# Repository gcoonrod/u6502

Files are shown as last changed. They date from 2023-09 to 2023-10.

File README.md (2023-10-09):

# u6502 - Single Board Computer
Very basic 6502 SBC based on the [design](http://wilsonminesco.com/6502primer/potpourri.html#BAS_CPU) by Garth Wilson.

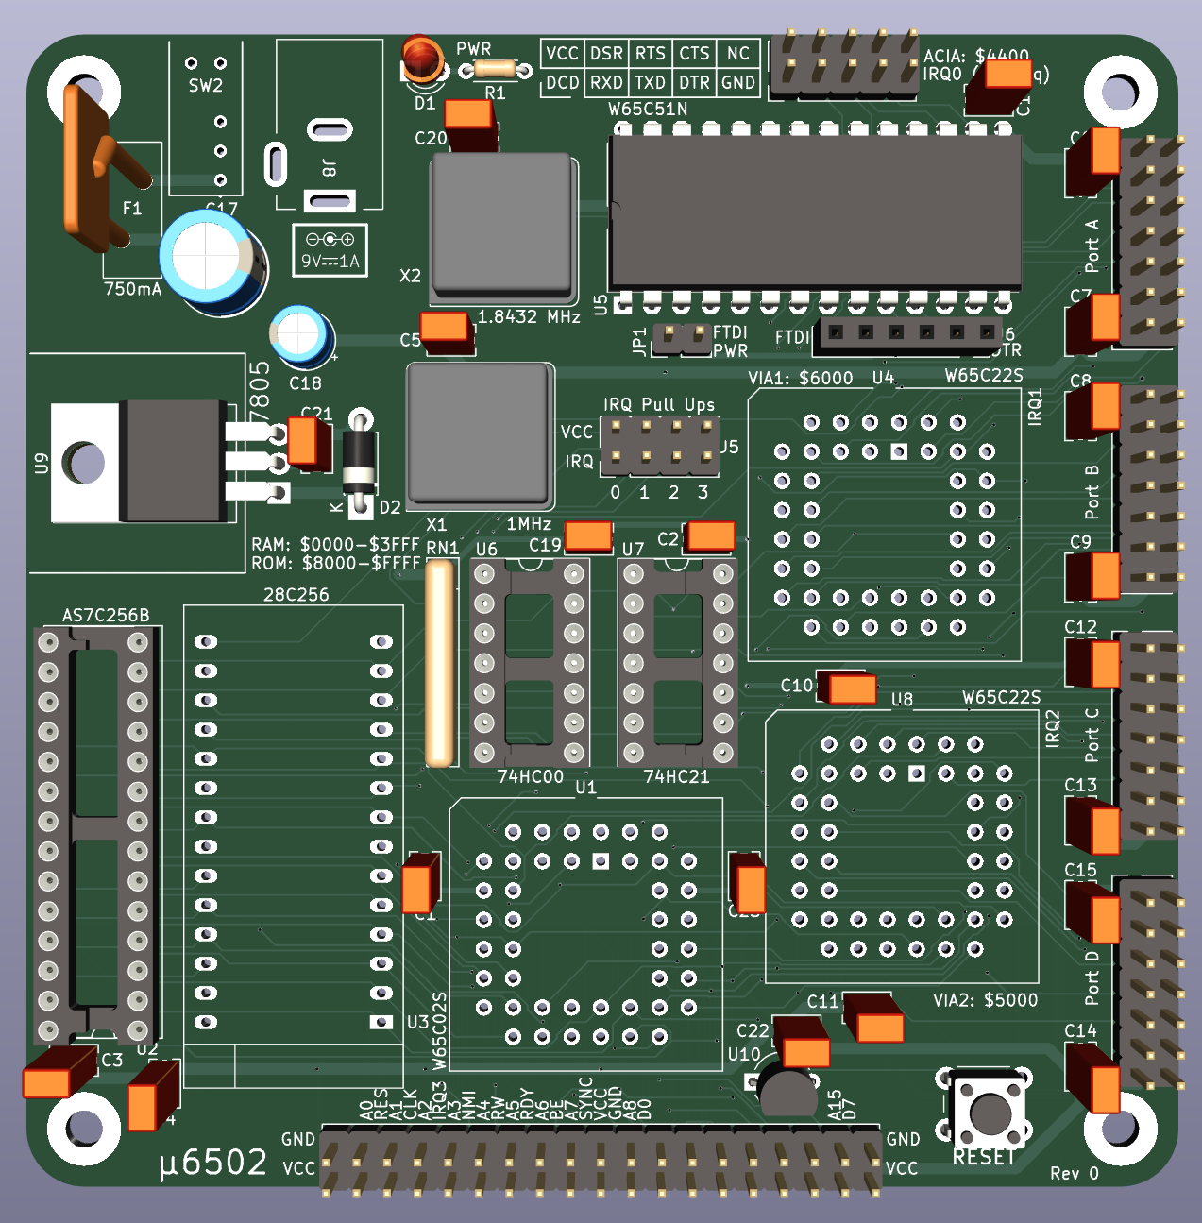
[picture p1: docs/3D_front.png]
PCB Render


## Project Status
A rev 0 board has been fabricated and assembled. Testing is in progress.

### Known Issues
- **LCD Display** - The LCD display correctly shows the two lines that are expected at power up but only displays a single line after a reset. Assumed to be a software issue involving the initialization logic for the LCD controller.
- **ACIA** - No TX traffic is observed from the ACIA. Currently unable to determine the reason. A logic analyzer connected to the chip select and register select signals for the ACIA _seem_ to indicate that the chip is being addressed correctly.

## Design Goals & Project Objectives

- Keep it _almost_ as simple as possible.
    - Start with a proven design to reduce the likelihood of errors.
    - Keep PCB size to less than 100mm^2 to minimize fabrication cost.
    - Use only parts that are currently in production and favor through hole components where possible.
- Support TTL RS232 UART with RTS/CTS flow control.
    - Allow for the loading of programs to memory from serial.
- Support PS2 protocol for keyboard through VIA.
- Support 16 x 2 character LCD display through VIA.
    - (Optional) Support larger character or graphics LCD display.
- (Optional) Support >4 MHz CPU speed.

## Repository Structure

- [boards](./boards/) - Kicad projects containing schematics and layout files for the SBC and any ancillary support devices.
- [docs](./docs/) - Documentation and static assests for the current iteration of the u6502.
- [firmware](./firmware/) - 6502 assembly files and build tooling (cc65) to produce ROMs for the u6502.
- [tools](./tools/) - Software utilities and Arduino sketches used to support the testing and development of the u6502.

## Addres Map

- RAM $0000:3FFF
- ACIA $4400:4403
- VIA2 $5000:500F
- VIA1 $6000:600F
- ROM $8000:FFFF

## Parts Selection

- CPU - W65C02S (PLCC) WDC current production 65C02
- Memory - AS7C256B-15PIN (DIP) SRAM chosen for package size more than speed
- ROM - Any 28C256 JEDEC compatible EEPROM (DIP) 
- Address Decoding - 74HC00 (DIP)
- IRQ Control - 74HC21 (DIP)
- GPIO - 2 W65C22S VIAs (PLCC)
- Serial IO - W65C51N ACIA (DIP)
- Power Regulation - LM7805 (TO220) compatible linear regulator
- Oscillators - 1MHz CPU clock & 1.8432 MHz for baud clock generation
- Reset control - DS1813 (TO92)

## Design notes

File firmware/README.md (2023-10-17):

# u6502 - Firmware

This directory contains the various programs, libraries, and utilities used by the u6502 SBC. 

## Build Process
Currently, all programs for the u6502 are assembled using the ca65 macro assembler which is a part of the [cc65 C Compiler](https://cc65.github.io/) project. ROMs are built in the following two step process:

1. Assembly - `ca65 -vvv --cpu 6502 -l {listingFilePath} -o {outputObjectFilePath} {sourceFilePath}`
2. Linking - `ld65 -o {outputBinaryPath} -C {linkerConfigFilePath} "{objectFilePath}"`
3. Flashing - The output from the linker is a binary that can be burned to the EEPROM (U3). This binary should work with any number of EEPROM programers, but I have only tested it with Xgpro.

A simple PowerShell script [build.ps1](build.ps1) is used to automate the build process in a Windows build environment. Usage of this script requires that the cc65 binaries be in the PATH environment variable. When using this script all output will go into the `build` directory.

### Linker Configuration
The cc65 linker (`ld65`) uses a configuration file to properly layout all of the assembled sources into a single output binary. I don't fully understand the syntax and capabilities of this configuration tool, but the [documentation](https://cc65.github.io/doc/ld65.html) is fairly good. In the case of the u6502, `roms/common/memmap.cfg` is the linker configuration. Of most importance here are the `MEMORY` and `SEGMENTS` sections which define the system's memory map and correlate any segments used in the assembly files with the correct memory locations.

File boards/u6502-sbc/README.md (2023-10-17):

# u6502 - SBC PCB Design Project
Kicad project for u6502.

[Schematic](../../docs/schematic.pdf)

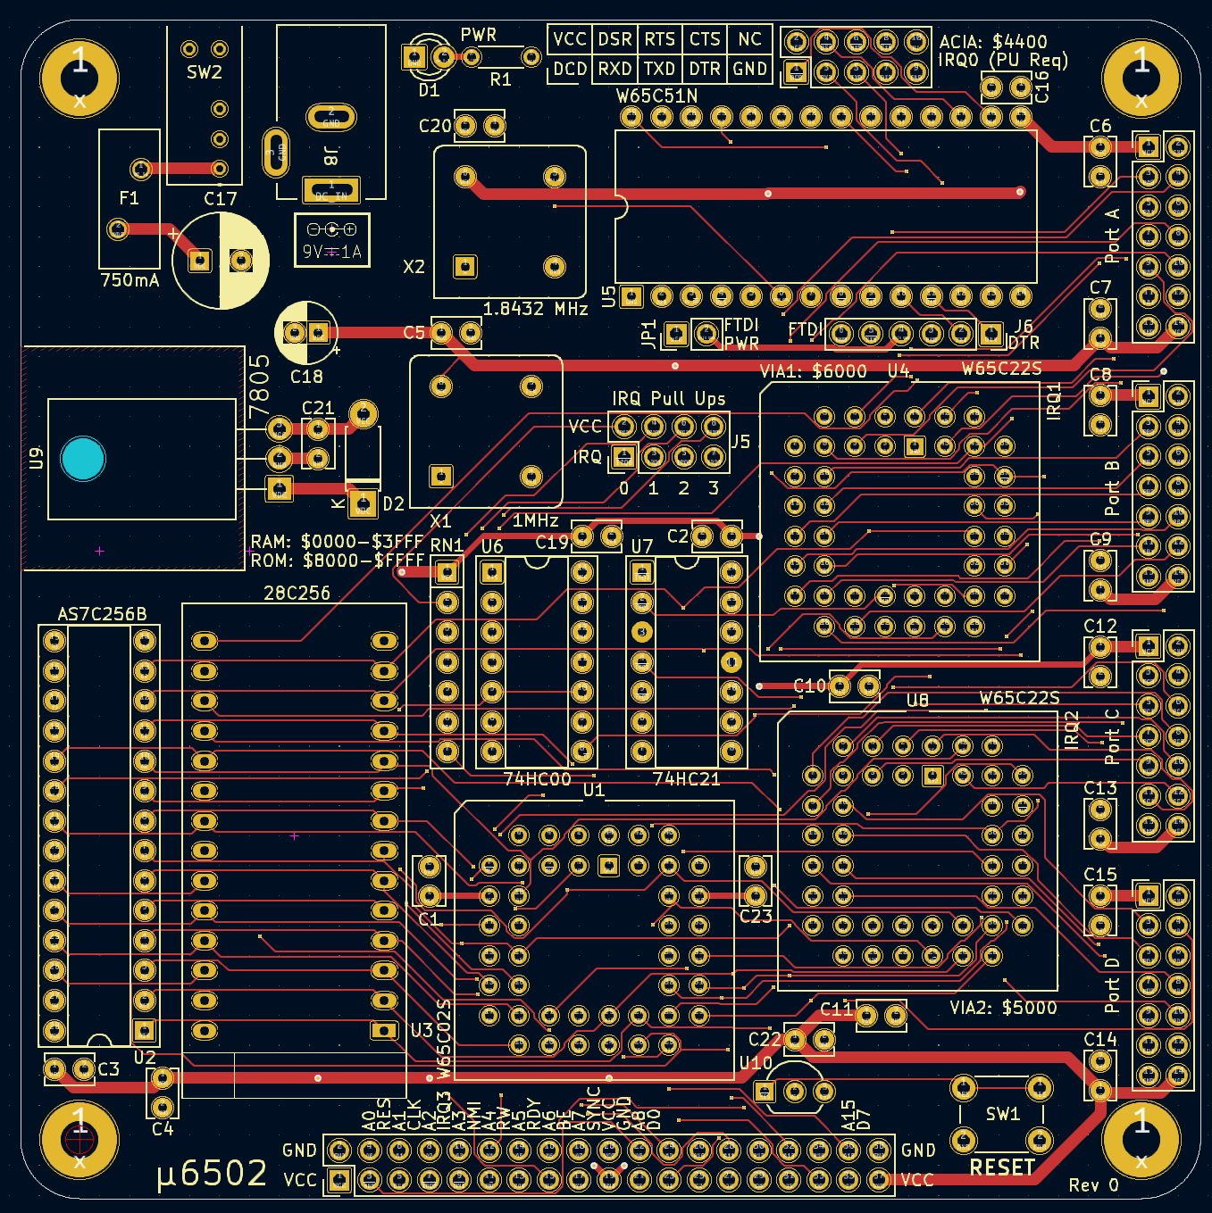
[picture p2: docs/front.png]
Front


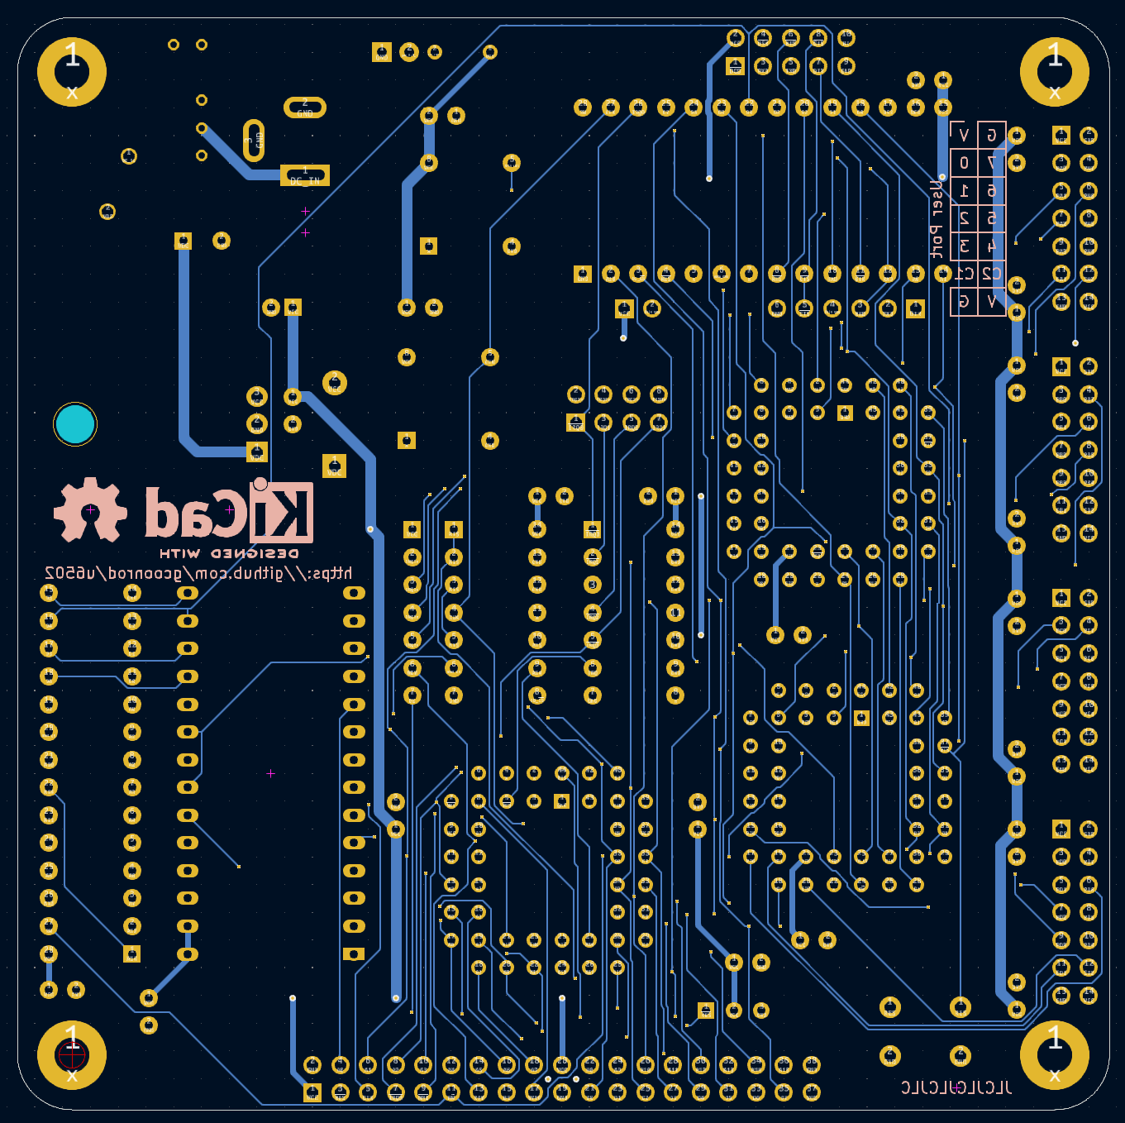
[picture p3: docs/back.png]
Back


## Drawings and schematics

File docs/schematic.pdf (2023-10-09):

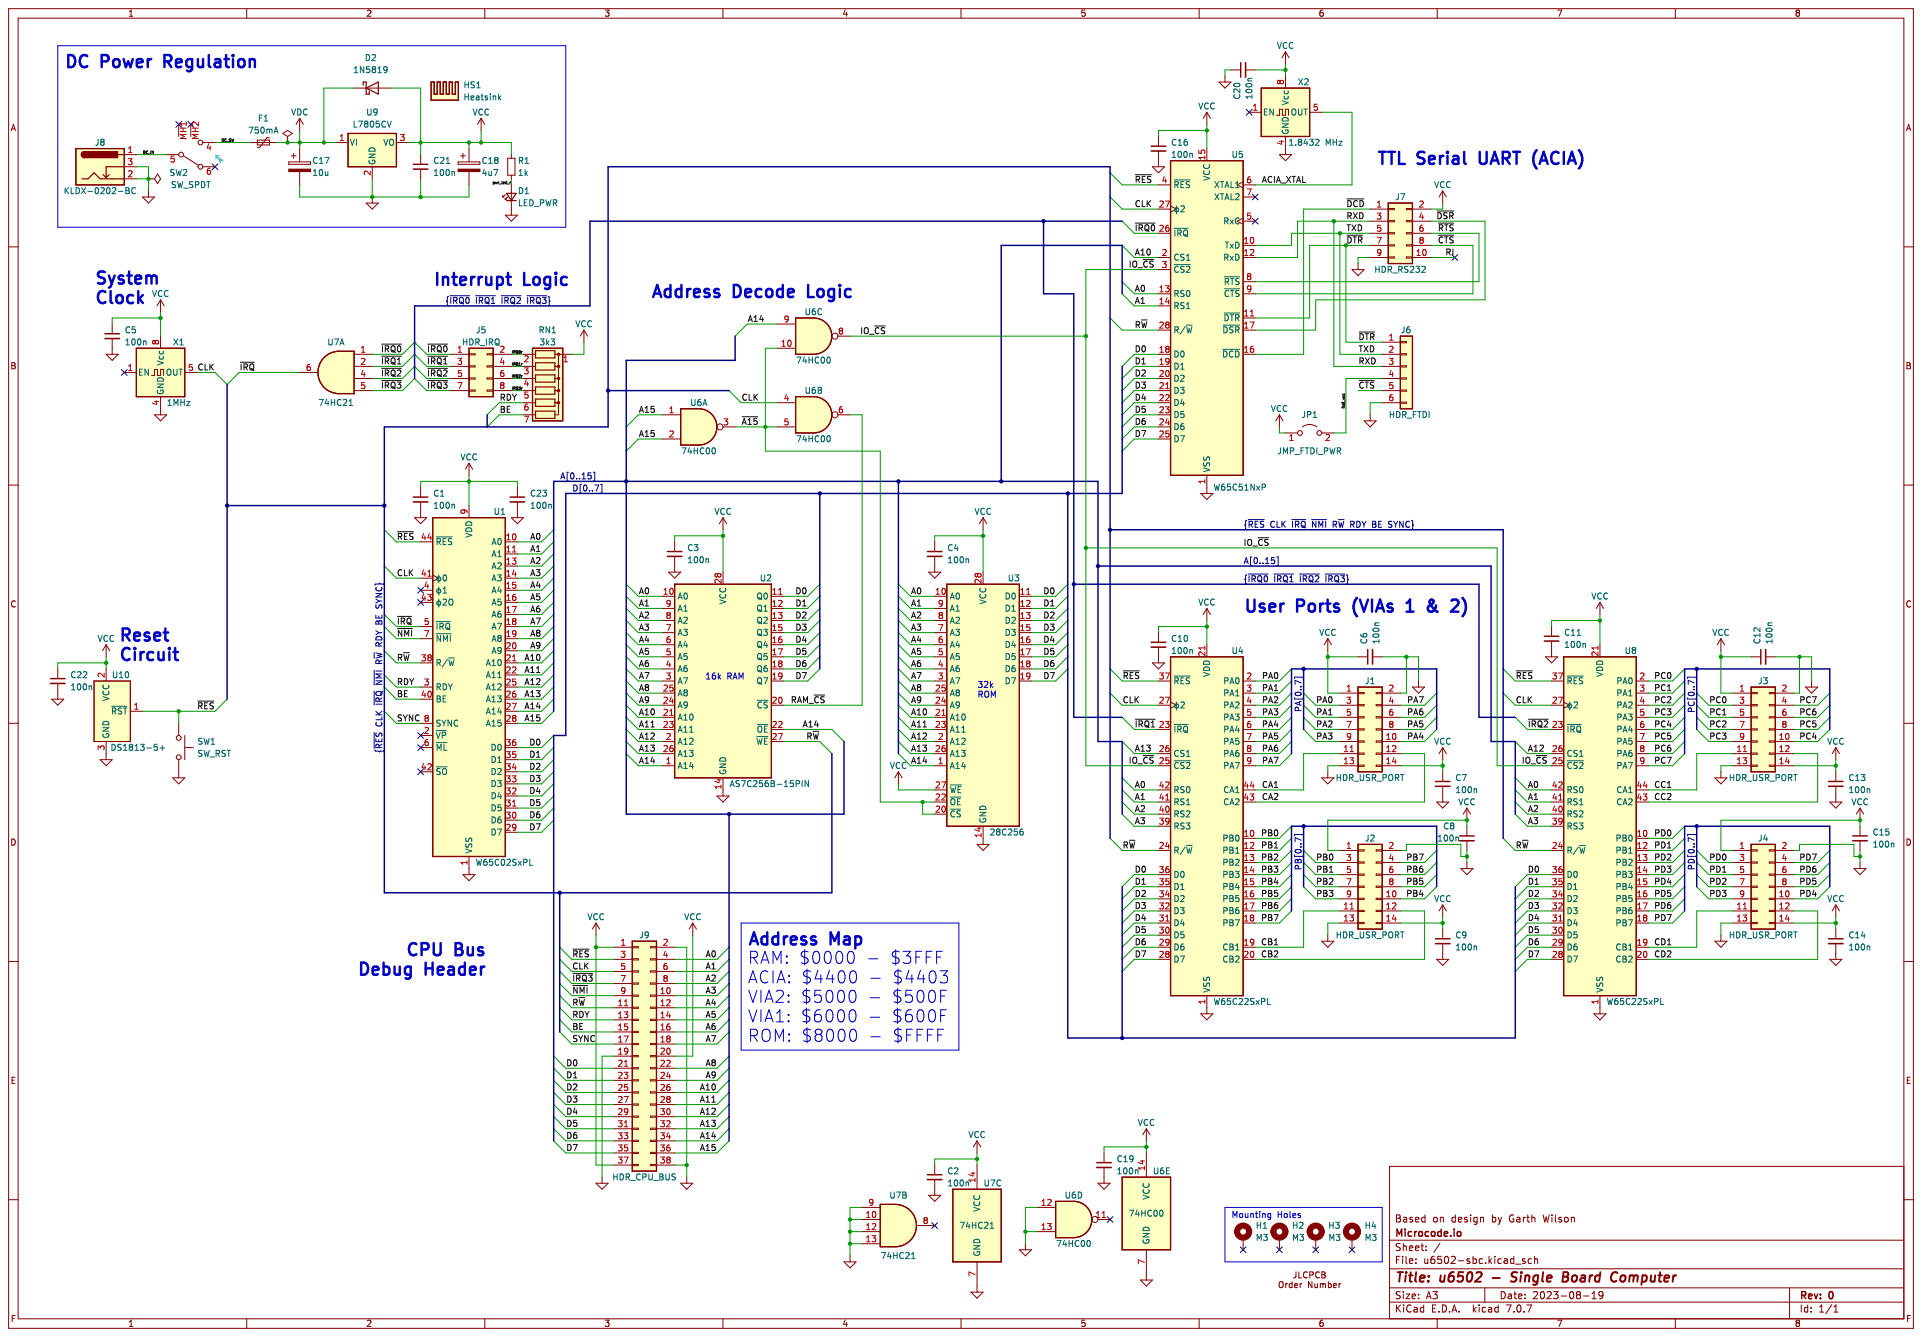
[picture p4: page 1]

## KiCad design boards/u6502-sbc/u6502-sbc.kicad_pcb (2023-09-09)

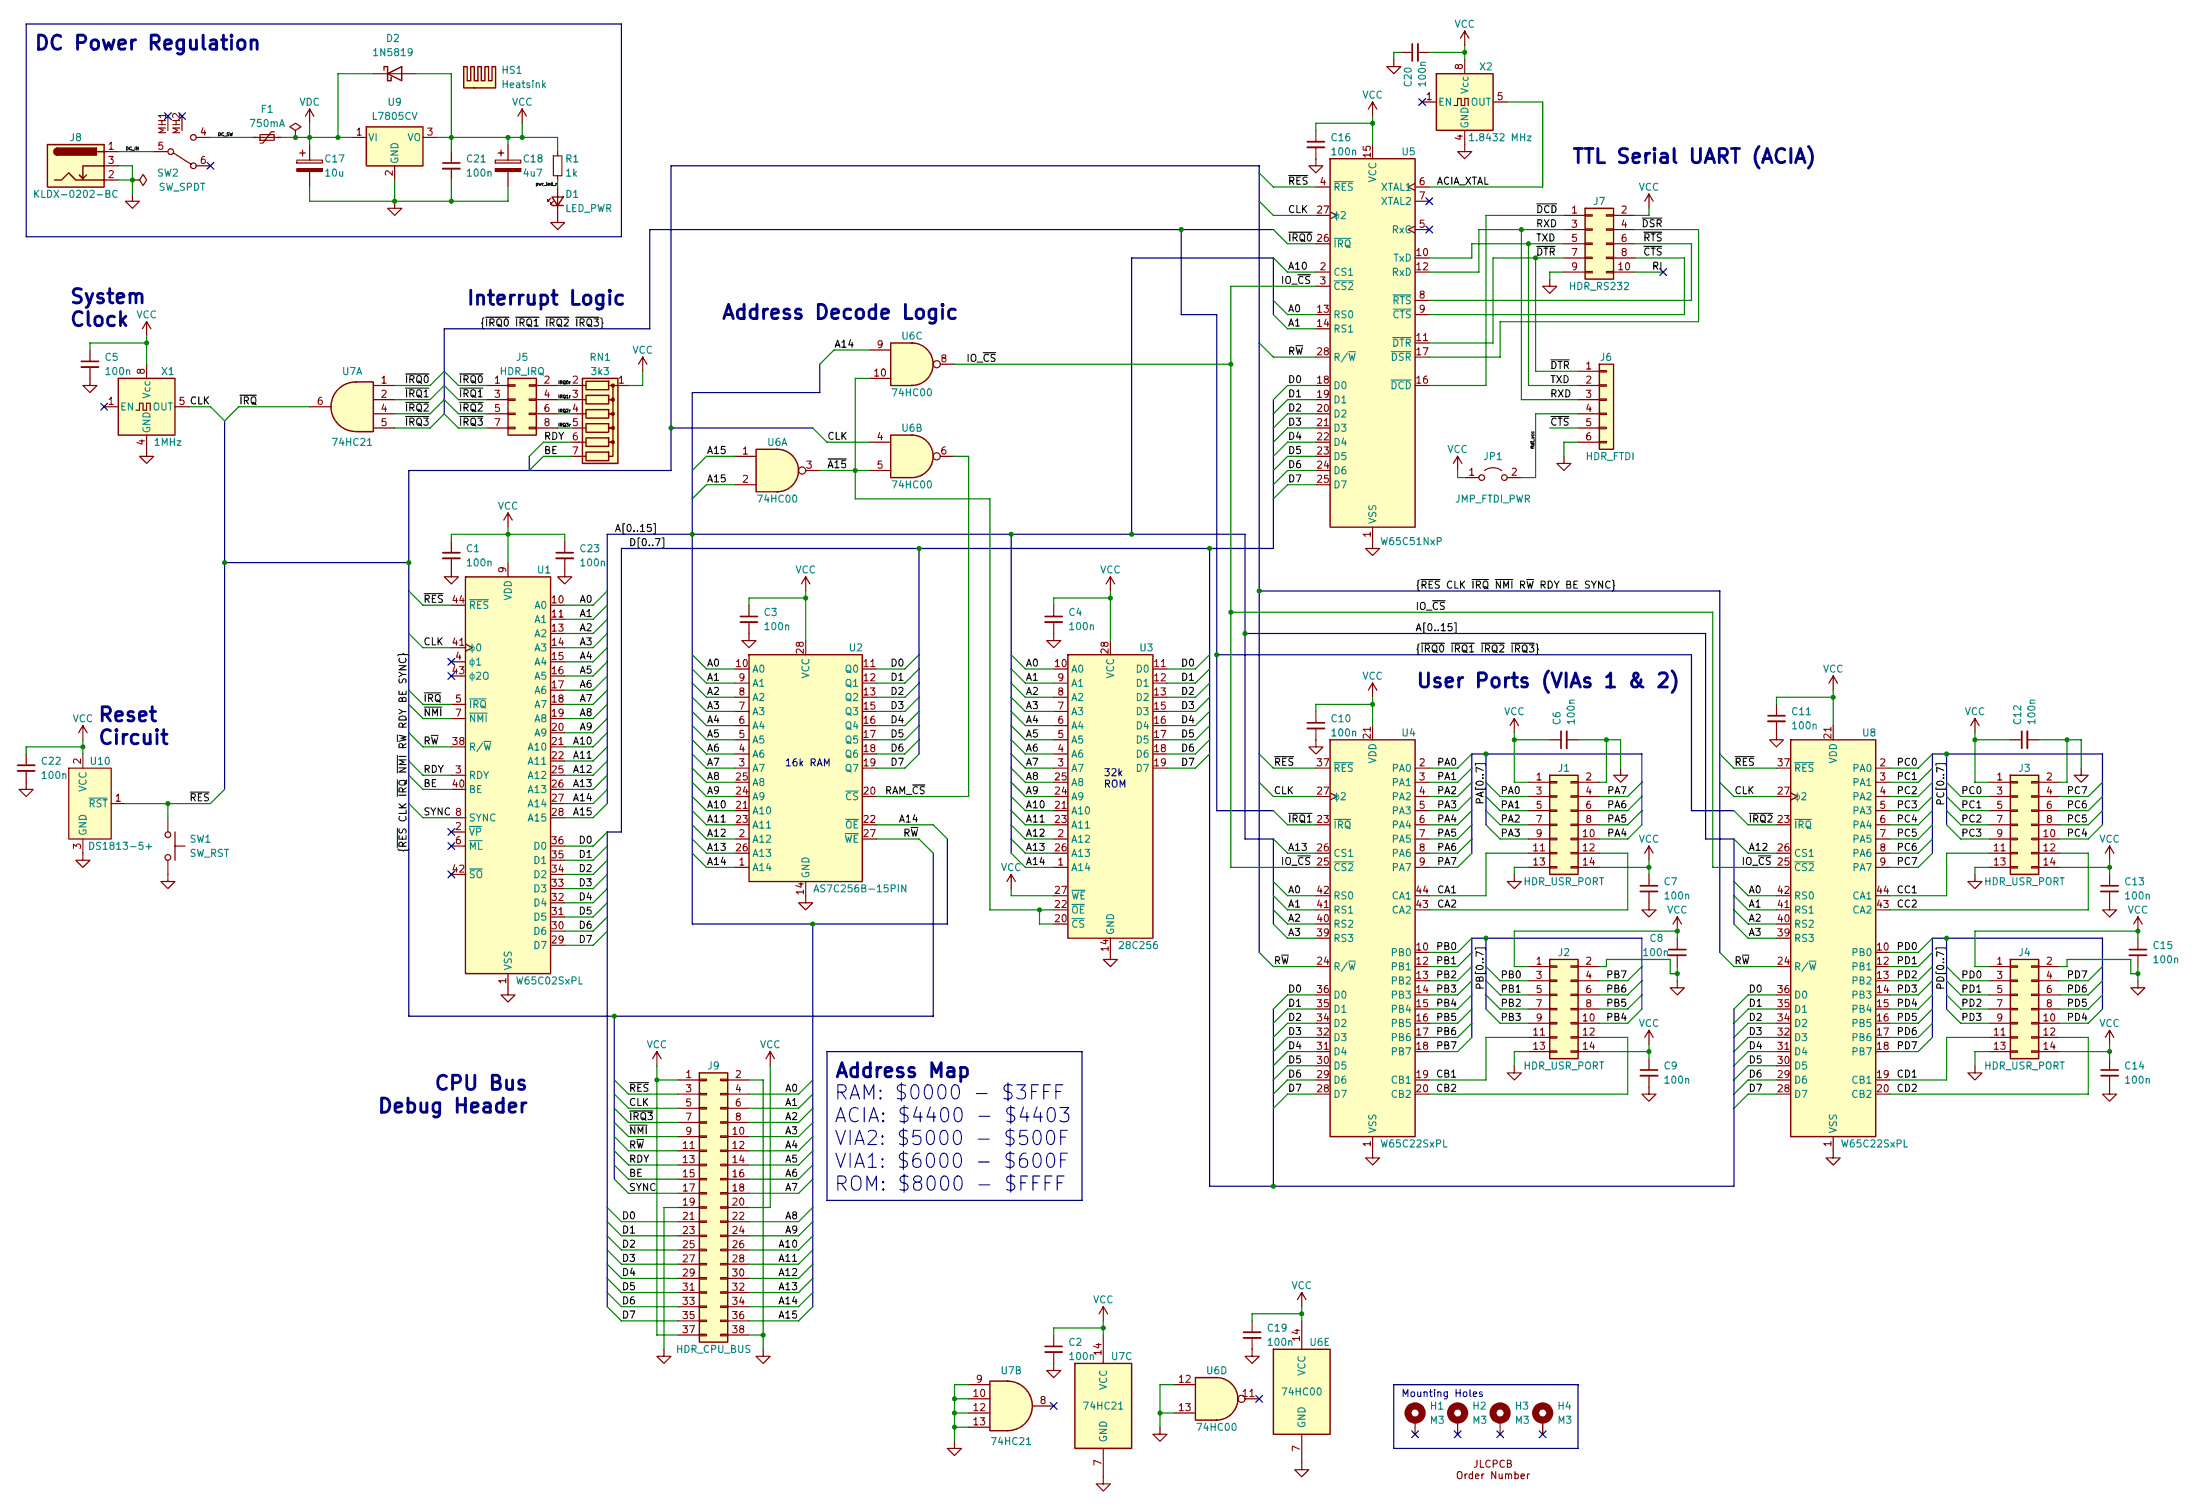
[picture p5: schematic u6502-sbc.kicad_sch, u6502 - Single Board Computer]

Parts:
C1, C2, C3, C4, C5, C6, C7, C8, C9, C10, C11, C12, C13, C14, C15, C16, C19, C20, C21, C22, C23: 100n; C_Rect_L4.0mm_W2.5mm_P2.50mm; Mfr Part K104K15X7RF5TL2; Mouser Part 594-K104K15X7RF5TL2
C17: 10u; CP_Radial_D8.0mm_P3.50mm; Mfr Part ESL106M200AG9AA; Mouser Part 80-ESL106M200AG9AA
C18: 4u7; CP_Radial_D5.0mm_P2.00mm; Mfr Part EEU-FR1H4R7B; Mouser Part 667-EEU-FR1H4R7B
D1: LED_PWR; LED_D3.0mm; Mfr Part WP132XID; Mouser Part 604-WP132XID
D2: 1N5819; D_DO-41_SOD81_P7.62mm_Horizontal; Mfr Part 1N5819-T; Mouser Part 621-1N5819
F1: 750mA; Fuse_BelFuse_0ZRE0075FF_L11.5mm_W4.8mm; Mfr Part 0ZRG0075FF1E; Mouser Part 530-0ZRG0075FF1E
H1, H2, H3, H4: M3; MountingHole_3.2mm_M3_Pad
HS1: Heatsink
J1, J2, J3, J4: HDR_USR_PORT; PinHeader_2x07_P2.54mm_Vertical
J5: HDR_IRQ; PinHeader_2x04_P2.54mm_Vertical
J6: HDR_FTDI; PinSocket_1x06_P2.54mm_Vertical
J7: HDR_RS232; PinHeader_2x05_P2.54mm_Vertical
J8: KLDX-0202-BC; BarrelJack_Kycon_KLDX-0202-xC_Horizontal; Mfr Part KLDX-0202-BC; Mouser Part 806-KLDX-0202-BC
J9: HDR_CPU_BUS; PinHeader_2x19_P2.54mm_Vertical
JP1: JMP_FTDI_PWR; PinHeader_1x02_P2.54mm_Vertical
R1: 1k; R_Axial_DIN0204_L3.6mm_D1.6mm_P5.08mm_Horizontal
RN1: 3k3; R_Array_SIP7
SW1: SW_RST; SW_PUSH_6mm
SW2: SW_SPDT; GW12RCV; Mfr Part GW12RCV; Mouser Part 633-GW12RCV
SYM1: OrderNumber
U1: W65C02SxPL; PLCC-44_THT-Socket
U2: AS7C256B-15PIN; DIP-28_W7.62mm_Socket
U3: 28C256; Aries 28-526-10; Mfr Part 28-526-10; Mouser Part 535-28-526-10
U4, U8: W65C22SxPL; PLCC-44_THT-Socket
U5: W65C51NxP; DIP-28_W15.24mm
U6: 74HC00; DIP-14_W7.62mm_Socket; Mfr Part SN74HC00AN; Mouser Part 595-SN74HC00AN
U7: 74HC21; DIP-14_W7.62mm_Socket; Mfr Part SN74HC21N; Mouser Part 595-SN74HC21N
U9: L7805CV; TO-220-3_Horizontal_TabDown; Mfr Part L7805CV; Mouser Part 511-L7805CV
U10: DS1813-5+; TO-92_Inline_Wide; Mfr Part DS1813-5+; Mouser Part 700-DS1813-5T&R
X1: 1MHz; Oscillator_DIP-8
X2: 1.8432 MHz; Oscillator_DIP-8; Mfr Part MXO45HS-3C-1M8432; Mouser Part 774-MXO45HS-3C-1.8

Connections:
/A0: J9.4, U1.10 (A0), U2.10 (A0), U3.10 (A0), U4.42 (RS0), U5.13 (RS0), U8.42 (RS0); also elsewhere on the board
/A1: J9.6, U1.11 (A1), U2.9 (A1), U3.9 (A1), U4.41 (RS1), U5.14 (RS1), U8.41 (RS1); also elsewhere on the board
/A2: J9.8, U1.13 (A2), U2.8 (A2), U3.8 (A2), U4.40 (RS2), U8.40 (RS2); also elsewhere on the board
/A3: J9.10, U1.14 (A3), U2.7 (A3), U3.7 (A3), U4.39 (RS3), U8.39 (RS3); also elsewhere on the board
/A4: J9.12, U1.15 (A4), U2.6 (A4), U3.6 (A4); also elsewhere on the board
/A5: J9.14, U1.16 (A5), U2.5 (A5), U3.5 (A5); also elsewhere on the board
/A6: J9.16, U1.17 (A6), U2.4 (A6), U3.4 (A6); also elsewhere on the board
/A7: J9.18, U1.18 (A7), U2.3 (A7), U3.3 (A7); also elsewhere on the board
/A8: J9.22, U1.19 (A8), U2.25 (A8), U3.25 (A8); also elsewhere on the board
/A9: J9.24, U1.20 (A9), U2.24 (A9), U3.24 (A9); also elsewhere on the board
/A10: J9.26, U1.21 (A10), U2.21 (A10), U3.21 (A10), U5.2 (CS1); also elsewhere on the board
/A11: J9.28, U1.22 (A11), U2.23 (A11), U3.23 (A11); also elsewhere on the board
/A12: J9.30, U1.25 (A12), U2.2 (A12), U3.2 (A12), U8.26 (CS1); also elsewhere on the board
/A13: J9.32, U1.26 (A13), U2.26 (A13), U3.26 (A13), U4.26 (CS1); also elsewhere on the board
/A14: J9.34, U1.27 (A14), U2.1 (A14), U2.22 (~OE), U3.1 (A14), U6.9; also elsewhere on the board
/A15: J9.36, U1.28 (A15), U6.1, U6.2; also elsewhere on the board
/ACIA_XTAL: U5.6 (XTAL1), X2.5 (OUT)
/BE: J9.15, RN1.7 (R6), U1.40 (BE); also elsewhere on the board
/CA1: J1.11, U4.44 (CA1)
/CA2: J1.12, U4.43 (CA2)
/CB1: J2.11, U4.19 (CB1)
/CB2: J2.12, U4.20 (CB2)
/CC1: J3.11, U8.44 (CA1)
/CC2: J3.12, U8.43 (CA2)
/CD1: J4.11, U8.19 (CB1)
/CD2: J4.12, U8.20 (CB2)
/CLK: J9.5, U1.41 (ϕ0), U4.27 (ϕ2), U5.27 (ϕ2), U6.4, U8.27 (ϕ2), X1.5 (OUT); also elsewhere on the board
/D0: J9.21, U1.36 (D0), U2.11 (Q0), U3.11 (D0), U4.36 (D0), U5.18 (D0), U8.36 (D0); also elsewhere on the board
/D1: J9.23, U1.35 (D1), U2.12 (Q1), U3.12 (D1), U4.35 (D1), U5.19 (D1), U8.35 (D1); also elsewhere on the board
/D2: J9.25, U1.34 (D2), U2.13 (Q2), U3.13 (D2), U4.34 (D2), U5.20 (D2), U8.34 (D2); also elsewhere on the board
/D3: J9.27, U1.33 (D3), U2.15 (Q3), U3.15 (D3), U4.32 (D3), U5.21 (D3), U8.32 (D3); also elsewhere on the board
/D4: J9.29, U1.32 (D4), U2.16 (Q4), U3.16 (D4), U4.31 (D4), U5.22 (D4), U8.31 (D4); also elsewhere on the board
/D5: J9.31, U1.31 (D5), U2.17 (Q5), U3.17 (D5), U4.30 (D5), U5.23 (D5), U8.30 (D5); also elsewhere on the board
/D6: J9.33, U1.30 (D6), U2.18 (Q6), U3.18 (D6), U4.29 (D6), U5.24 (D6), U8.29 (D6); also elsewhere on the board
/D7: J9.35, U1.29 (D7), U2.19 (Q7), U3.19 (D7), U4.28 (D7), U5.25 (D7), U8.28 (D7); also elsewhere on the board
/DC_IN: J8.1, SW2.5 (COM)
/DC_SW: F1.1, SW2.4 (NO)
/IO_~CS: U4.25 (~CS2), U5.3 (~CS2), U6.8, U8.25 (~CS2)
/IRQ0r: J5.2, RN1.2 (R1)
/IRQ1r: J5.4, RN1.3 (R2)
/IRQ2r: J5.6, RN1.4 (R3)
/IRQ3r: J5.8, RN1.5 (R4)
/PA0: J1.3, U4.2 (PA0)
/PA1: J1.5, U4.3 (PA1)
/PA2: J1.7, U4.4 (PA2)
/PA3: J1.9, U4.5 (PA3)
/PA4: J1.10, U4.6 (PA4)
/PA5: J1.8, U4.7 (PA5)
/PA6: J1.6, U4.8 (PA6)
/PA7: J1.4, U4.9 (PA7)
/PB0: J2.3, U4.10 (PB0)
/PB1: J2.5, U4.12 (PB1)
/PB2: J2.7, U4.13 (PB2)
/PB3: J2.9, U4.14 (PB3)
/PB4: J2.10, U4.15 (PB4)
/PB5: J2.8, U4.16 (PB5)
/PB6: J2.6, U4.17 (PB6)
/PB7: J2.4, U4.18 (PB7)
/PC0: J3.3, U8.2 (PA0)
/PC1: J3.5, U8.3 (PA1)
/PC2: J3.7, U8.4 (PA2)
/PC3: J3.9, U8.5 (PA3)
/PC4: J3.10, U8.6 (PA4)
/PC5: J3.8, U8.7 (PA5)
/PC6: J3.6, U8.8 (PA6)
/PC7: J3.4, U8.9 (PA7)
/PD0: J4.3, U8.10 (PB0)
/PD1: J4.5, U8.12 (PB1)
/PD2: J4.7, U8.13 (PB2)
/PD3: J4.9, U8.14 (PB3)
/PD4: J4.10, U8.15 (PB4)
/PD5: J4.8, U8.16 (PB5)
/PD6: J4.6, U8.17 (PB6)
/PD7: J4.4, U8.18 (PB7)
/RAM_~CS: U2.20 (~CS), U6.6
/RDY: J9.13, RN1.6 (R5), U1.3 (RDY); also elsewhere on the board
/RI: J7.10
/RXD: J6.3, J7.3, U5.12 (RxD)
/R~W: J9.11, U1.38 (R/~W), U2.27 (~WE), U4.24 (R/~W), U5.28 (R/~W), U8.24 (R/~W); also elsewhere on the board
/SYNC: J9.17, U1.8 (SYNC); also elsewhere on the board
/TXD: J6.2, J7.5, U5.10 (TxD)
/ftdi_vcc: J6.4, JP1.2 (B)
/pwr_led_r: D1.2 (A), R1.2
/~A15: U3.20 (~CS), U3.22 (~OE), U6.3, U6.5, U6.10
/~CTS: J6.5, J7.8, U5.9 (~CTS)
/~DCD: J7.1, U5.16 (~DCD)
/~DSR: J7.4, U5.17 (~DSR)
/~DTR: J6.1, J7.7, U5.11 (~DTR)
/~IRQ0: J5.1, U5.26 (~IRQ), U7.1
/~IRQ1: J5.3, U4.23 (~IRQ), U7.2
/~IRQ2: J5.5, U7.4, U8.23 (~IRQ)
/~IRQ3: J5.7, J9.7, U7.5; also elsewhere on the board
/~IRQ: U1.5 (~IRQ), U7.6
/~NMI: J9.9, U1.7 (~NMI); also elsewhere on the board
/~RES: J9.3, SW1.1, U1.44 (~RES), U4.37 (~RES), U5.4 (~RES), U8.37 (~RES), U10.1 (~RST); also elsewhere on the board
/~RTS: J7.6, U5.8 (~RTS)
GND: C1.2, C2.2, C3.2, C4.2, C5.2, C6.2, C7.2, C8.2, C9.2, C10.2, C11.2, C12.2, C13.2, C14.2, C15.2, C16.2, C17.2, C18.2, C19.2, C20.1, C21.2, C22.2, C23.2, D1.1 (K), J1.2, J1.13, J2.2, J2.13, J3.2, J3.13, J4.2, J4.13, J6.6, J7.9, J8.2, J8.3, J9.2, J9.19, J9.38, SW1.2, U1.1 (VSS), U1.23 (VSS), U1.24 (VSS), U2.14 (GND), U3.14 (GND), U4.1 (VSS), U5.1 (VSS), U6.7 (GND), U6.12, U6.13, U7.7 (GND), U7.9, U7.10, U7.12, U7.13, U8.1 (VSS), U9.2 (GND), U10.3 (GND), X1.4 (GND), X2.4 (GND); also elsewhere on the board
VCC: C1.1, C2.1, C3.1, C4.1, C5.1, C6.1, C7.1, C8.1, C9.1, C10.1, C11.1, C12.1, C13.1, C14.1, C15.1, C16.1, C18.1, C19.1, C20.2, C21.1, C22.1, C23.1, D2.2 (A), J1.1, J1.14, J2.1, J2.14, J3.1, J3.14, J4.1, J4.14, J7.2, J9.1, J9.20, J9.37, JP1.1 (A), R1.1, RN1.1 (common), U1.9 (VDD), U1.37 (VDD), U2.28 (VCC), U3.27 (~WE), U3.28 (VCC), U4.21 (VDD), U5.15 (VCC), U6.14 (VCC), U7.14 (VCC), U8.21 (VDD), U9.3 (VO), U10.2 (VCC), X1.8 (Vcc), X2.8 (Vcc); also elsewhere on the board
VDC: C17.1, D2.1 (K), F1.2, U9.1 (VI)

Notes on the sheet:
User Ports (VIAs 1 & 2)
TTL Serial UART (ACIA)
Interrupt Logic
Mounting Holes
RAM: $0000 - $3FFF ACIA: $4400 - $4403 VIA2: $5000 - $500F VIA1: $6000 - $600F ROM: $8000 - $FFFF
Address Decode Logic
CPU Bus Debug Header
Reset Circuit
32k ROM
DC Power Regulation
16k RAM
Address Map
System Clock

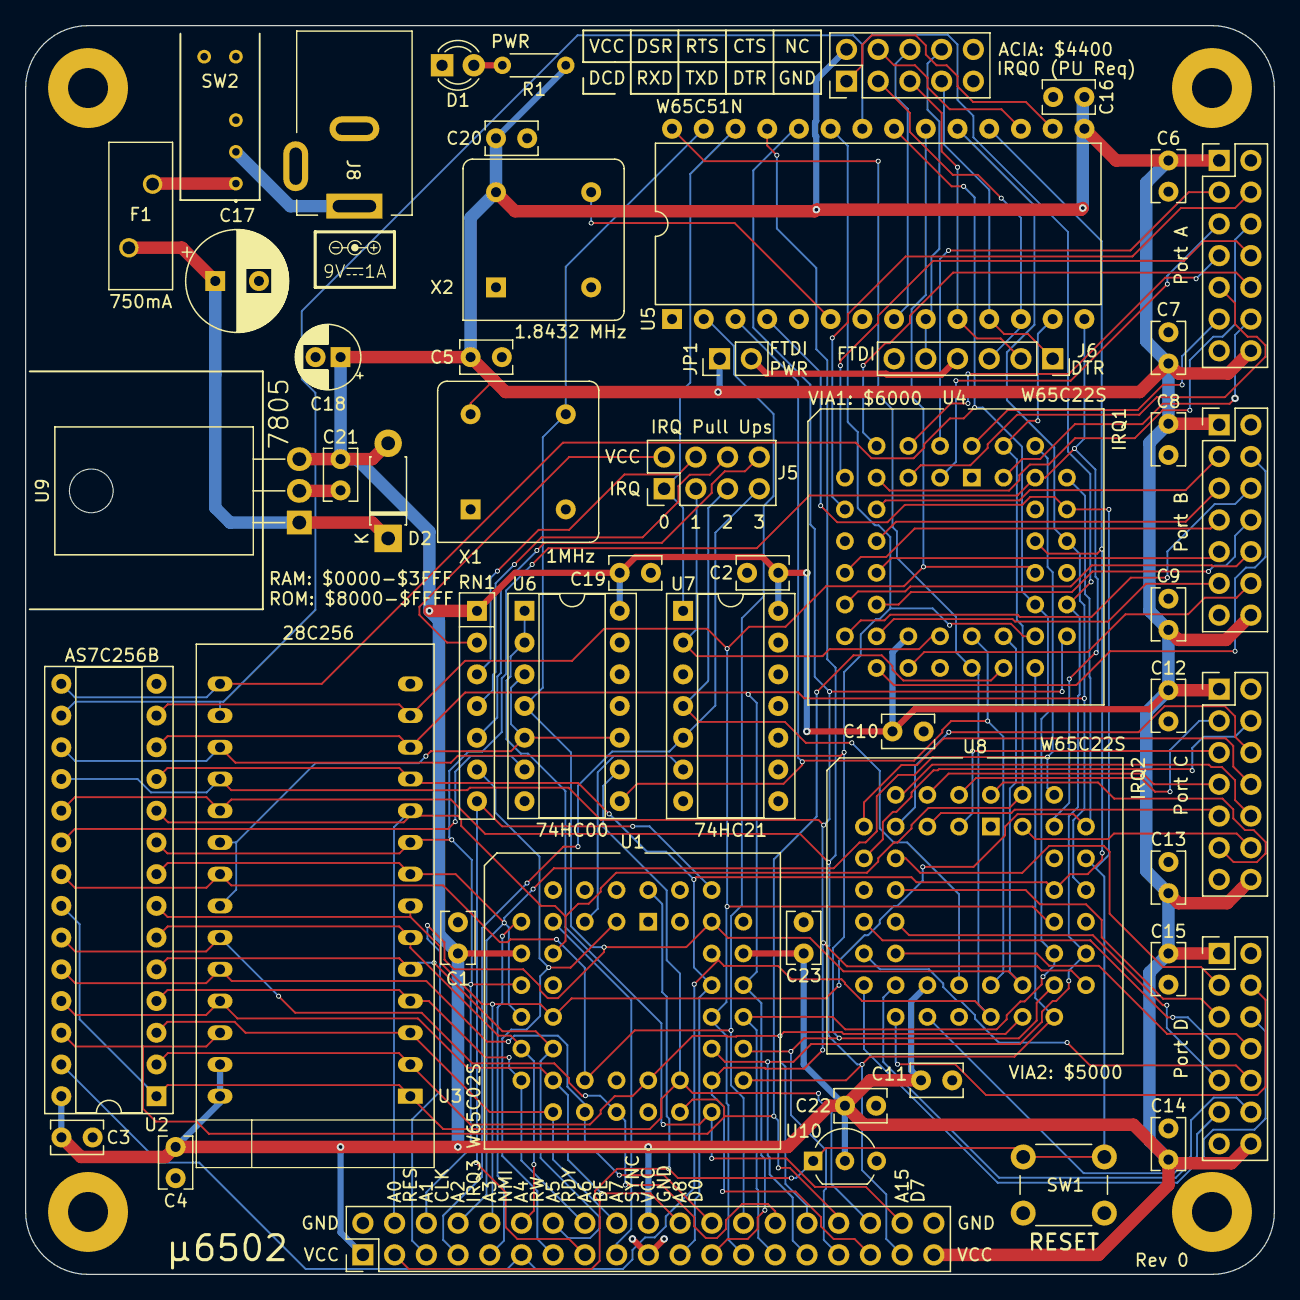
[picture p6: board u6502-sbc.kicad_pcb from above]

Board: 4 copper layers, 100.0 x 100.0 mm, 57 parts (1 on the bottom side), 98 nets.

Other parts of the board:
locked: HDR_CPU_BUS; PinHeader_2x19_P2.54mm_Vertical

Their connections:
/A0: locked.4; also elsewhere on the board
/A1: locked.6; also elsewhere on the board
/A2: locked.8; also elsewhere on the board
/A3: locked.10; also elsewhere on the board
/A4: locked.12; also elsewhere on the board
/A5: locked.14; also elsewhere on the board
/A6: locked.16; also elsewhere on the board
/A7: locked.18; also elsewhere on the board
/A8: locked.22; also elsewhere on the board
/A9: locked.24; also elsewhere on the board
/A10: locked.26; also elsewhere on the board
/A11: locked.28; also elsewhere on the board
/A12: locked.30; also elsewhere on the board
/A13: locked.32; also elsewhere on the board
/A14: locked.34; also elsewhere on the board
/A15: locked.36; also elsewhere on the board
/BE: locked.15; also elsewhere on the board
/CLK: locked.5; also elsewhere on the board
/D0: locked.21; also elsewhere on the board
/D1: locked.23; also elsewhere on the board
/D2: locked.25; also elsewhere on the board
/D3: locked.27; also elsewhere on the board
/D4: locked.29; also elsewhere on the board
/D5: locked.31; also elsewhere on the board
/D6: locked.33; also elsewhere on the board
/D7: locked.35; also elsewhere on the board
/RDY: locked.13; also elsewhere on the board
/R~W: locked.11; also elsewhere on the board
/SYNC: locked.17; also elsewhere on the board
/~IRQ3: locked.7; also elsewhere on the board
/~NMI: locked.9; also elsewhere on the board
/~RES: locked.3; also elsewhere on the board
GND: locked.2, locked.19, locked.38; also elsewhere on the board
VCC: locked.1, locked.20, locked.37; also elsewhere on the board

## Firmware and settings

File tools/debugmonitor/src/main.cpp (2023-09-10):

/**
 * @file main.cpp
 * @brief Arduino Mega2560 Sketch to monitor the address, data, and control lines of the 6502 bus.
 *
 * Debug Monitor for 6502 Bus (Mini 6502 SBC rev 1.0)
 *
 * This sketch monitors the address, data, and control lines of the 6502 bus. During setup it will hold
 * the 6502 in reset, configure the address, data, and control lines as inputs, and then release the reset
 * and begin monitoring the bus. The sketch will print the address, data, and control lines to the serial.
 */

#include <Arduino.h>

// General Definitions
#define BAUD_RATE 115200
#define WAIT_FOR_SERIAL 1
//#define INTERCEPT

// Control Line Pin Definitions
#define CLK_PIN 2
#define RWB_PIN 3
#define RESB_PIN 18

// Address Line Pin Definitions (A0-A15 = 22-52 even)
const uint8_t ADDR_BUS[] = {22, 24, 26, 28, 30, 32, 34, 36, 38, 40, 42, 44, 46, 48, 50, 52};

// Data Line Pin Definitions (D0-D7 = 23-37 odd)
const uint8_t DATA_BUS[] = {23, 25, 27, 29, 31, 33, 35, 37};

// Global Variables
volatile uint16_t clk_count = 0;
volatile uint8_t new_clk_cycle = 0;
volatile uint8_t clk_state = 0;
volatile uint8_t rwb_state = 0;
volatile uint8_t resb_state = 0;
volatile uint16_t addr = 0;
volatile uint8_t data = 0;
volatile uint8_t data_bus_dir = INPUT;

void clk_change_isr(void);
void clk_rise_isr(void);
void clk_fall_isr(void);
void resb_change_isr(void);
void print_word_bin(uint16_t word);
void print_byte_bin(uint8_t byte);
void print_word_hex(uint16_t word);
void print_byte_hex(uint8_t byte);

//

void setup(void)
{

  // Disable Interrupts
  noInterrupts();

  // Configure Reset Pin first and pull low to hold 6502 in reset
  // pinMode(RESB_PIN, OUTPUT);
  // digitalWrite(RESB_PIN, LOW);

  // Configure Control Lines
  pinMode(CLK_PIN, INPUT);
  pinMode(RWB_PIN, INPUT);
  pinMode(RESB_PIN, INPUT_PULLUP);

  // Configure Address Lines
  for (uint8_t i = 0; i < sizeof(ADDR_BUS); i++)
  {
    pinMode(ADDR_BUS[i], INPUT);
  }

  // Configure Data Lines
  for (uint8_t i = 0; i < sizeof(DATA_BUS); i++)
  {
    pinMode(DATA_BUS[i], data_bus_dir);
  }

  // Start the Serial Monitor
  Serial.begin(BAUD_RATE);
  if (WAIT_FOR_SERIAL)
  {
    while (!Serial)
    {
      ; // Wait for Serial Monitor to connect
    }
  }

  // Setup Complete
  Serial.println(F("Debug Monitor for 6502 Bus (Mini 6502 SBC rev 1.0)"));
  Serial.println(F("Releasing Reset..."));

  // Release Reset
  // digitalWrite(RESB_PIN, HIGH);
  // pinMode(RESB_PIN, INPUT_PULLUP);

  // Attach Interrupts
  attachInterrupt(digitalPinToInterrupt(CLK_PIN), clk_change_isr, CHANGE);
  attachInterrupt(digitalPinToInterrupt(RESB_PIN), resb_change_isr, CHANGE);

  // Enable Interrupts
  interrupts();
}

void loop(void)
{

  // If in reset, do nothing
  if (resb_state == LOW)
  {
    Serial.println("RESET");
    clk_count = 0;
    delay(100);
    return;
  }

  // If we've reached 65535 clock cycles, reset the counter
  if (clk_count == 65535)
  {
    Serial.println("PC Rollover");
    clk_count = 0;
  }
}

// ISR Handlers

/**
 * The 65C02 clock cycle starts with a falling edge of the clock signal. The address and RWB will be valid on the
 * bus after 30ns max (tADS). TODO figure out all the timings. For now we'll be slow enough that it doesn't matter.
 */
void clk_change_isr(void)
{
  noInterrupts();
  // Read the clock state first
  clk_state = digitalRead(CLK_PIN);
  switch (clk_state)
  {
  case LOW:
    clk_fall_isr();
    break;
  case HIGH:
    clk_rise_isr();
    break;
  }
  interrupts();
}

void clk_fall_isr(void)
{
  new_clk_cycle = 1;
  // Read the Address Bus and Control Line states
  addr = 0;
  for (uint8_t i = 0; i < sizeof(ADDR_BUS); i++)
  {
    addr |= (digitalRead(ADDR_BUS[i]) << i);
  }
  rwb_state = digitalRead(RWB_PIN);

  // If not in reset, set the data bus direction based on the RWB state
  if (resb_state == HIGH)
  {
    if (rwb_state == HIGH)
    {
      data_bus_dir = OUTPUT;
    }
    else
    {
      data_bus_dir = INPUT;
    }
  }
}

void clk_rise_isr(void)
{
  clk_state = HIGH;
  // Read the Data Bus state (we don't do any writing yet)
  if (new_clk_cycle == 1)
  {

    if (resb_state == HIGH)
    {
#ifdef INTERCEPT
      if (data_bus_dir == INPUT)
      {
        data = 0;
        for (uint8_t i = 0; i < sizeof(DATA_BUS); i++)
        {
          pinMode(DATA_BUS[i], INPUT);
          data |= (digitalRead(DATA_BUS[i]) << i);
        }
      }
      else
      {
        // Intercept the any read from $FFFC, $FFFD
        // and set the PC to $0000
        if (addr == 0xFFFC || addr == 0xFFFD)
        {
          // Set the data bus to ouput and write $00
          data = 0x00;
          for (uint8_t i = 0; i < sizeof(DATA_BUS); i++)
          {
            pinMode(DATA_BUS[i], OUTPUT);
            digitalWrite(DATA_BUS[i], LOW);
          }
        }
        else
        {
          // Set the data bus to output and write $EA (NOP)
          data = 0xEA;
          for (uint8_t i = 0; i < sizeof(DATA_BUS); i++)
          {
            pinMode(DATA_BUS[i], OUTPUT);
            digitalWrite(DATA_BUS[i], (data >> i) & 0x01);
          }
        }
      }
#else
      data = 0;
      for (uint8_t i = 0; i < sizeof(DATA_BUS); i++)
      {
        data |= (digitalRead(DATA_BUS[i]) << i);
      }
#endif

      // Print the address, data, and control lines
      // Always pad the address and PC to 16 bits, and the data to 8 bits
      Serial.print(F("PC: "));
      print_word_hex(clk_count);
      Serial.print(F(" ADDR: "));
      print_word_bin(addr);
      Serial.print(F(" "));
      print_word_hex(addr);
      Serial.print(F(" DATA: "));
      print_byte_bin(data);
      Serial.print(F(" "));
      print_byte_hex(data);
      Serial.println(rwb_state ? F(" r") : F(" W"));
    }

    // Clear the new_clk_cycle flag
    new_clk_cycle = 0;
    clk_count++;
  }
}

void resb_change_isr(void)
{
  resb_state = digitalRead(RESB_PIN);
}

void print_word_bin(uint16_t word)
{
  // Convert the word (two bytes) to a 16 charater string representing the binary value and print
  char word_str[17];
  for (uint8_t i = 0; i < 16; i++)
  {
    word_str[i] = (word & (1 << (15 - i))) ? '1' : '0';
  }
  word_str[16] = '\0';
  Serial.print(word_str);
}

void print_word_hex(uint16_t word)
{
  // Convert the word (two bytes) to a 4 charater string representing the hex value and print
  char word_str[5];
  sprintf(word_str, "%04X", word);
  Serial.print(word_str);
}

void print_byte_bin(uint8_t byte)
{
  // Convert the byte (one byte) to an 8 charater string representing the binary value and print
  char byte_str[9];
  for (uint8_t i = 0; i < 8; i++)
  {
    byte_str[i] = (byte & (1 << (7 - i))) ? '1' : '0';
  }
  byte_str[8] = '\0';
  Serial.print(byte_str);
}

void print_byte_hex(uint8_t byte)
{
  // Convert the byte (one byte) to a 2 charater string representing the hex value and print
  char byte_str[3];
  sprintf(byte_str, "%02X", byte);
  Serial.print(byte_str);
}

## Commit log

2023-08-25 Initial layout and routing wip
    [u6502-sbc.kicad_pcb, u6502-sbc.kicad_sch]
2023-08-28 Board rev 0 ordered
    [u6502-sbc.kicad_pcb, u6502-sbc.kicad_sch]
2023-09-09 Add basic build tooling.
    [memmap.cfg]
2023-09-09 Minor updates from rev 0.
    [u6502-sbc.kicad_pcb]
2023-09-10 hello-world works.
    [memmap.cfg]
